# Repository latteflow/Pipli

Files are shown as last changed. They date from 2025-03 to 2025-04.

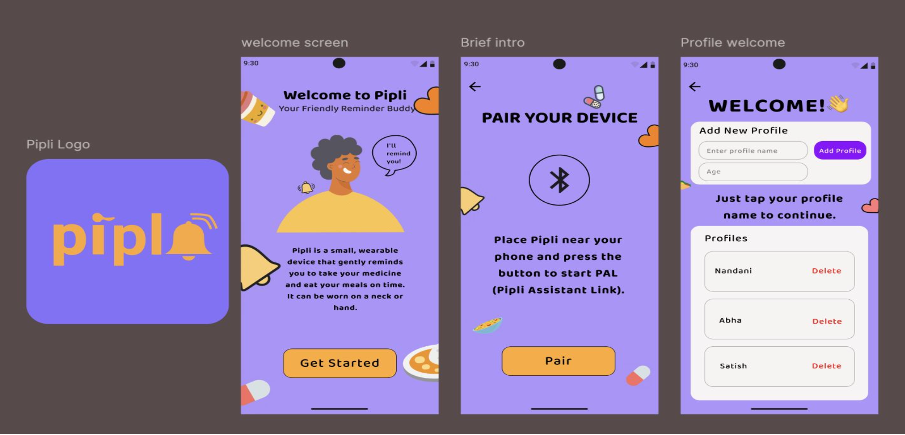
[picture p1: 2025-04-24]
App/Pipli/image.png

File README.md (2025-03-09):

# Pipli \- Medicine reminder device for elderly people.

A Device to help elderly people  
Github link: [https://github.com/latteflow/Pipli](https://github.com/latteflow/Pipli)  
Drawio file: 

Contributors: Nandani & Latteflow Team   
Started on: 21 January 2025

## Problem Statement 

Nowadays, most elderly people live alone at home. They often cannot leave because they are emotionally attached to their homes. However, living alone makes it difficult for them to take care of themselves. 

To solve this problem, we can create a low-cost device that provides timely reminders for meals and medication. This device can be worn on the wrist like a watch, making it easy to carry and use. It uses a low-cost microcontroller and a small ubiquitous replaceable battery. It can be easily connected to a smartphone via Bluetooth, where the reminders can be pre-programmed and saved in advance. The device will be easily accessible, ensuring elderly individuals receive important reminders without hassle.

The design and the code will be made open-source, such that everyone can access and easily replicate the design to help. 

We can create a device app called Pipli, which will feature a reminder system for important notifications. This app is designed to be highly convenient for elderly users, ensuring that they can easily set and receive reminders for various tasks and events. By focusing on a user-friendly interface with large buttons and clear instructions, Pipli will cater specifically to the needs of seniors, helping them manage their daily schedules effectively.

Approach 

![][image1]

This device will have a note chart for important items such as medication and food reminders. We can create a mockup of the app using Figma to ensure that everything is easy to understand. The app will include several features, such as buttons for help, sound notifications, feedback, and options for listening, downloading, or sharing information. This design will enhance user experience and make it more accessible for elderly users.

Do UX mockup of the app on the Figma 

1 Start writing a detailed approach 

- [ ] What is required   
- [ ] A smartphone with an application   
- [ ] Customizable options such as \- Repeat intervals, Advance alerts and Sound notifications.  
- [ ] A Pipli device to manage 

2 What functionality will the device have 

- [ ] Haptic feedback, ie, vibration   
- [ ] Sound   
- [ ] A button for Help  
- [ ] A button to listen   
- [ ] To create a new note  
- [ ] Delete Option  
- [ ] Share Option   
- [ ] Download Option

3 What components will it have 

- [ ] An MCU with WiFi/Bluetooth  
- [ ] Vibration motor   
- [ ] Sound   
- [ ] Button 

## 

## Electronics

Once each sensor and actuator has been tested and programmed individually, we have to design a PCB, which needs to be printed.   
Finally, we will solder every component and test it. When everything is working, then we will incorporate it into the mechanical housing 

KiCAD: [https://www.kicad.org/](https://www.kicad.org/)

![][image2]  
 Example PCB 

## Firmware

For programming and all: [https://platformio.org/](https://platformio.org/)

It has an extension for VS Code, please sign up and try to get it working

Website to simulate and run your program: [https://wokwi.com/esp32](https://wokwi.com/esp32)

## Mechanical Design 

Autodesk Fusion:   
[https://www.autodesk.com/in/products/fusion-360/overview](https://www.autodesk.com/in/products/fusion-360/overview)

Once the electronics are ready, we will start the mechanical design process. We will be utilizing the 3D printer for design iterations. 

Meanwhile, you should start designing the sketch, iterate, and think about user interactions and user experience. 

![][image3]

A Mockup of the Pipli device with Buttons

Fusion 360 Link for the design: 

[https://a360.co/4kiht4b](https://a360.co/4kiht4b)

## Application

Android / IOS   
[https://reactnative.dev/](https://reactnative.dev/)

We will have an app which will let the user connect and configure the reminders. It will be a primary way to connect to the device and save the program and reminders. Once the medicine course is over, it can be removed and a new medicine course can be saved for someone else. It will have the ability to connect to multiple devices.  

The app will be created in the React Native framework, such that both Android and IOS devices can work. 

UI / UX 

Figma:   
[https://www.figma.com/](https://www.figma.com/)

- [ ] PUT user interaction workflow here   

1. Press a button   
2. The device will wake up   
3. It will try to search for a new device   
4. If there is no device, then it will go into sleep mode   
5. Once the reminder comes close, it will wake up and try to play the sound/vibration sensor   
6. Once the user presses the button confirming they have taken medicine / do the work.   
7. Then it will go to sleep 

The user can ask for help by pressing the button   
If the device wakes and tries to connect with the smartphone, it will play the sound or send a notification that someone is in need of help.

## Components required 

ESP32

Tutorial: [https://randomnerdtutorials.com/projects-esp32/](https://randomnerdtutorials.com/projects-esp32/)

USB micro programmer / UBB C programmer 

LED 

Vibration motor: 

[https://robu.in/product/dc-vibration-motor-module/](https://robu.in/product/dc-vibration-motor-module/)

How to interface vibration motor with sensor: 

[https://thecustomizewindows.com/2021/08/esp32-and-coin-vibrator-motor/](https://thecustomizewindows.com/2021/08/esp32-and-coin-vibrator-motor/) 

Sound sensor: 

[https://www.elprocus.com/sound-sensor-working-and-its-applications/](https://www.elprocus.com/sound-sensor-working-and-its-applications/)

 Sound buzzers: 

[https://esp32io.com/tutorials/esp32-piezo-buzzer](https://esp32io.com/tutorials/esp32-piezo-buzzer)

[https://robu.in/product/5v-active-alarm-buzzer-module-arduino/](https://robu.in/product/5v-active-alarm-buzzer-module-arduino/)

Buttons or Tactile switch: 

[https://robu.in/product/6x6x5-tactile-push-button-switch/](https://robu.in/product/6x6x5-tactile-push-button-switch/)

Rechargeable battery: 

[https://robu.in/product/400mah-pcm-protected-micro-li-po-battery-2/](https://robu.in/product/400mah-pcm-protected-micro-li-po-battery-2/)

Lipo charger with USB C: 

[https://robu.in/product/lipo-charger-with-usc-c-type-jack/](https://robu.in/product/lipo-charger-with-usc-c-type-jack/)

[https://www.flyrobo.in/tp4056-1a-li-ion-lithium-battery-charging-module-with-current-protection-type-c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\&gQT=1](https://www.flyrobo.in/tp4056-1a-li-ion-lithium-battery-charging-module-with-current-protection-type-c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)

[https://robu.in/product/tp4056-1a-li-ion-lithium-battery-charging-module-with-current-protection-type-c/](https://robu.in/product/tp4056-1a-li-ion-lithium-battery-charging-module-with-current-protection-type-c/)

3d Printing service: [https://robu.in/product/3d-printing-service/](https://robu.in/product/3d-printing-service/)

2 List key steps

* Break down the journey into individual steps   
  Pipli Device \- Medicine Remainder  
- [ ] User interaction workflow  
1. Open the  phone go to the  bluetooth option and press the bluetooth  and open and see the Pipli device

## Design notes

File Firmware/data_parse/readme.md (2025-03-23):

Esp32: pinouts
http://randomnerdtutorials.com/esp32-pinout-reference-gpios/

Software dependencies: 
Make 
Platform IO 
Pio CLI 

## ESP32 
1. Make bluetooth work 
2. File sytem to Save JSON 
3. 

when pressing mechanical switches, it will debounce. The switch turn on and off multiple times before it settles.
This is due to the mechanical nature of the switch. To debounce, we can use a software solution.
The software solution is to wait for a certain amount of time before we consider the switch to be stable. This is called debouncing.

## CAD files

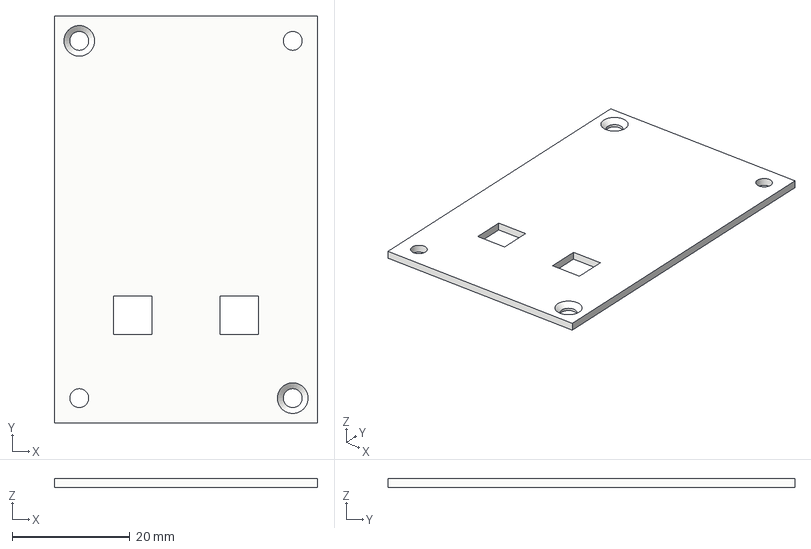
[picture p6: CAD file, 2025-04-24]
Mechanical/Pipli - TOP.step
44.6 x 69.0 x 1.50 mm

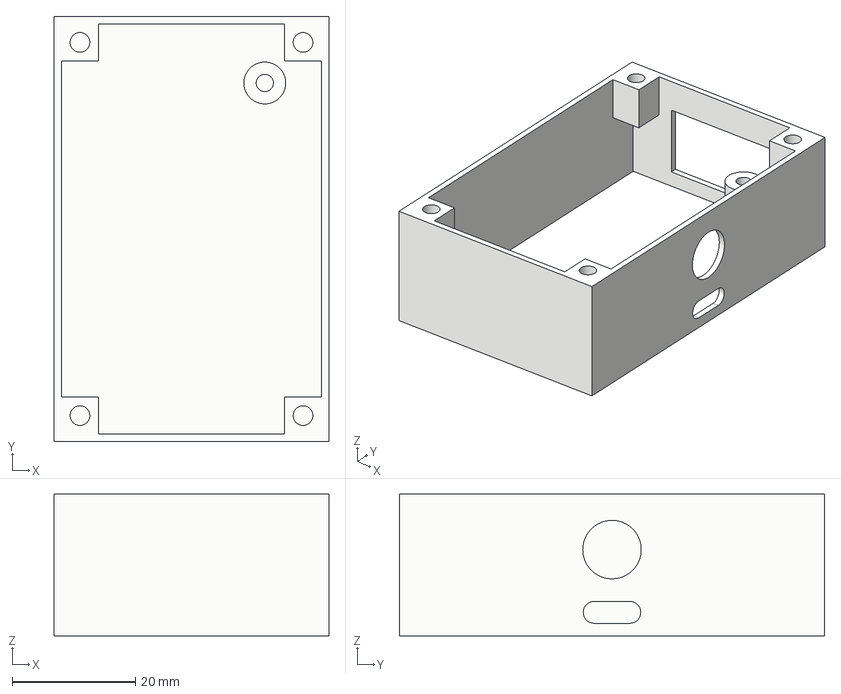
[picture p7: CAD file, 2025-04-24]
Mechanical/Pipli - BOTTOM.step
44.6 x 69.0 x 23.0 mm

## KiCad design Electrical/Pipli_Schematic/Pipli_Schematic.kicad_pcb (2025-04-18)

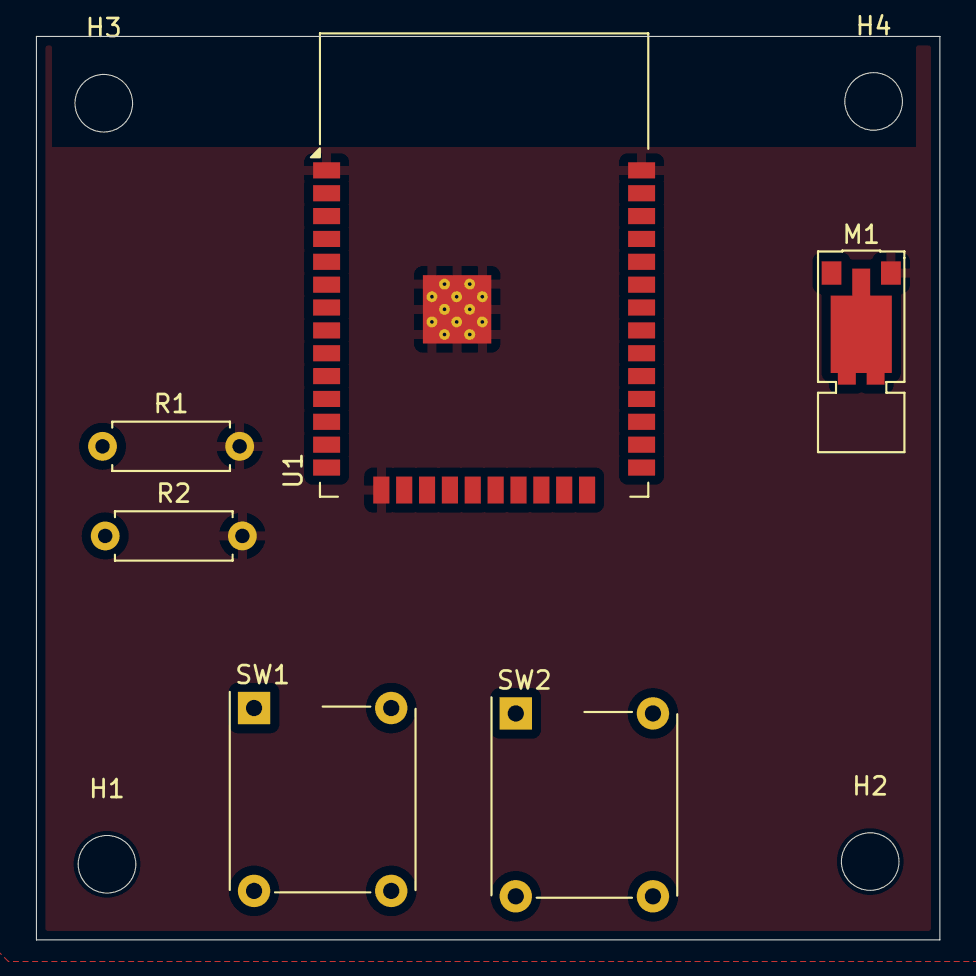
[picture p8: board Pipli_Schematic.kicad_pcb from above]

Board: 2 copper layers, 50.2 x 50.2 mm, 10 parts (0 on the bottom side), 4 nets, no tracks yet.

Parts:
H1, H2, H3, H4: M3; MountingHole_3.2mm_M3
M1: Motor_DC; Vybronics_VZ30C1T8219732L
R1, R2: 18k; R_Axial_DIN0207_L6.3mm_D2.5mm_P7.62mm_Horizontal
SW1, SW2: SW; SW_MEC_5GTH9
U1: ESP32-WROOM-32D

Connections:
/INPUT_SW_1: R1.1, SW1.1 (A), SW1.2 (A), U1.6 (IO34)
/INPUT_SW_2: R2.1, SW2.1 (A), SW2.2 (A), U1.37 (IO23)
/VIB_POS: M1.1 (+), U1.30 (IO18)
GND: M1.2 (-), R1.2, R2.2, U1.1 (GND), U1.15 (GND), U1.38 (GND), U1.39 (GND)

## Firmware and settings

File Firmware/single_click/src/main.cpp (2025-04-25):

#include <Arduino.h>

// bluetooth related
#include <BLEDevice.h>
#include <BLEServer.h>
#include <BLEUtils.h>
#include <BLE2902.h>

// srorage related (Optional but recommended for persistence)
#include "FS.h"
#include <LittleFS.h>

// JSON data library
#include <ArduinoJson.h>

#include <algorithm> // Needed for std::min

#define FORMAT_LITTLEFS_IF_FAILED true
#define SCHEDULE_FILENAME "/schedule.json"
#define MILLIS_COUNTER_FILENAME "/millis_counter.dat" // File to store last millis()

unsigned long lastMillisSaveTime = 0; // Timer for saving millis counter

BLEServer *pServer = NULL;
BLECharacteristic *pCharacteristic = NULL;
bool deviceConnected = false;
bool oldDeviceConnected = false;

// --- BLE Chunking Settings ---
const size_t BLE_CHUNK_SIZE = 20;
const int BLE_CHUNK_DELAY_MS = 30; // Delay between sending chunks (adjust as needed)

// See the following for generating UUIDs:
// https://www.uuidgenerator.net/

#define SERVICE_UUID "4fafc201-1fb5-459e-8fcc-c5c9c331914b"
#define CHARACTERISTIC_UUID "beb5483e-36e1-4688-b7f5-ea07361b26a8"

#define VIBRATION_PIN 19
#define PAIR_PIN 23 // Not used in reminder logic, but kept for consistency
#define USER_PIN 34 // Used for responding to reminders
#define LED 2

#define BLINK_DURATION_MS 50 // How long the LED stays on during a blink

// --- Reminder System Settings ---
#define VIBRATION_DURATION_MS 5000 // How long to vibrate for a reminder
#define RESPONSE_TIMEOUT_MS 15000  // How long to wait for user input after vibration

#define UPDATE_REQUEST_CMD "SEND_UPDATE"

// --- State Machine ---
enum State
{
    STATE_IDLE,                // Waiting for a schedule or connection
    STATE_PROCESSING_SCHEDULE, // Actively checking reminder times
    STATE_VIBRATING,           // Currently vibrating for a reminder
    STATE_WAITING_RESPONSE,    // Waiting for user button press after vibration
    STATE_SENDING_UPDATE       // Preparing/sending updated schedule
};
State currentState = STATE_IDLE;

// -- -Schedule Data-- -
// Use JsonDocument for flexibility. Adjust size as needed.
JsonDocument scheduleDoc; // Increased size for schedule + responses
bool scheduleLoaded = false;
unsigned long scheduleReceiveTime = 0; // millis() when schedule was received/loaded

// --- Reminder Tracking ---
int currentMedIndex = -1;
int currentTimeIndex = -1;
unsigned long stateTimer = 0;                // Used for vibration duration and response timeout
unsigned long nextReminderDueTimeMillis = 0; // Stores the absolute time of the next reminder
unsigned long lastCountdownPrintMillis = 0;  // Timer for printing countdown

// -- -Function Prototypes-- -
void blinkLed();
void startVibration();
void stopVibration();
bool loadSchedule();
bool saveSchedule();
void processSchedule();
void sendUpdate(bool changeStateToIdleOnSuccess = true);
// void moveToNextReminder(); // No longer needed
void handleReceivedData(const std::string &data);

bool saveMillisCounter();
unsigned long loadMillisCounter();

// Stream opearator (kept from original)
template <class T>
inline Print &operator<<(Print &obj, T arg)
{
    obj.print(arg);
    return obj;
}
template <>
inline Print &operator<<(Print &obj, float arg)
{
    obj.print(arg, 4);
    return obj;
}
// It preserves the original LED state if it was meant to be ON (connected)
void blinkLed()
{
    bool originalState = digitalRead(LED);
    digitalWrite(LED, !originalState);
    delay(BLINK_DURATION_MS);
    digitalWrite(LED, originalState);
}

void startVibration()
{
    Serial.println("Starting Vibration");
    digitalWrite(VIBRATION_PIN, HIGH);
}

void stopVibration()
{
    Serial.println("Stopping Vibration");
    digitalWrite(VIBRATION_PIN, LOW);
}

class MyServerCallbacks : public BLEServerCallbacks
{
    void onConnect(BLEServer *pServer)
    {
        deviceConnected = true;
        digitalWrite(LED, HIGH); // LED ON when connected
        Serial.println("Device Connected");
        // Optional: Maybe request schedule update on connect?
        // pCharacteristic->setValue("REQUEST_SCHEDULE");
        // pCharacteristic->notify();
    };

    void onDisconnect(BLEServer *pServer)
    {
        deviceConnected = false;
        digitalWrite(LED, LOW); // LED OFF when disconnected
        Serial.println("Device Disconnected - Restarting Advertising");
        // Reset state if needed when disconnected? Maybe not, allow processing offline.
        // currentState = STATE_IDLE;
        // scheduleLoaded = false;
        delay(500);                  // Give stack time
        pServer->startAdvertising(); // Restart advertising
    }
};

class MyCharacteristicCallbacks : public BLECharacteristicCallbacks
{
    void onWrite(BLECharacteristic *pCharacteristic)
    {
        std::string rxValue = pCharacteristic->getValue();
        if (rxValue.length() > 0)
        {
            Serial.println(" ");
            Serial.print("Received data: ");
            Serial.println(rxValue.c_str());
            blinkLed(); // Blink on any receive

            // --- Modification: Check for command first ---
            if (rxValue == UPDATE_REQUEST_CMD)
            {
                Serial.println("Received update request command.");
                // Attempt to send the update immediately if connected
                // sendUpdate() already checks for connection and loaded data
                sendUpdate(false);
            }
            else
            {
                // If it's not the command, assume it's a new schedule
                Serial.println("Data is not an update command, treating as new schedule.");
                handleReceivedData(rxValue);
            }
            // --- End Modification ---
        }
    }
};

// --- Function to save the current millis() counter ---
bool saveMillisCounter()
{
    unsigned long currentMillis = millis();
    File file = LittleFS.open(MILLIS_COUNTER_FILENAME, FILE_WRITE); // Open for writing (overwrite)
    if (!file)
    {
        Serial.println("Failed to open millis counter file for writing");
        return false;
    }

    // Write the current millis() value as binary data
    size_t bytesWritten = file.write((uint8_t *)&currentMillis, sizeof(currentMillis));
    file.close();

    if (bytesWritten == sizeof(currentMillis))
    {
        // Serial.printf("Millis counter saved: %lu\n", currentMillis); // Optional: Verbose logging
        return true;
    }
    else
    {
        Serial.println("Failed to write millis counter to file.");
        LittleFS.remove(MILLIS_COUNTER_FILENAME); // Attempt to remove potentially corrupted file
        return false;
    }
}

// --- Function to load the last saved millis() counter ---
unsigned long loadMillisCounter()
{
    if (!LittleFS.exists(MILLIS_COUNTER_FILENAME))
    {
        Serial.println("Millis counter file not found.");
        return 0; // Return 0 if no previous value exists
    }

    File file = LittleFS.open(MILLIS_COUNTER_FILENAME, FILE_READ);
    if (!file)
    {
        Serial.println("Failed to open millis counter file for reading");
        return 0;
    }

    unsigned long loadedMillis = 0;
    if (file.size() == sizeof(loadedMillis))
    {
        size_t bytesRead = file.read((uint8_t *)&loadedMillis, sizeof(loadedMillis));
        if (bytesRead != sizeof(loadedMillis))
        {
            Serial.println("Error reading millis counter file.");
            loadedMillis = 0; // Treat read error as if file didn't exist
        }
    }
    else
    {
        Serial.println("Millis counter file has incorrect size.");
        loadedMillis = 0; // Treat size error as if file didn't exist
    }

    file.close();

    if (loadedMillis > 0)
    {
        Serial.printf("Loaded last known millis: %lu\n", loadedMillis);
    }
    return loadedMillis;
}

// --- Schedule Handling Logic ---

void handleReceivedData(const std::string &data)
{
    Serial.println("Attempting to parse NEW schedule data string...");

    // --- Parse the incoming data string as a temporary array ---
    JsonDocument tempDoc; // Use a temporary document for the incoming array
    DeserializationError tempError = deserializeJson(tempDoc, data);
    if (tempError)
    {
        Serial.print(F("Initial parsing of received string failed: "));
        Serial.println(tempError.f_str());
        // Don't change state or clear existing valid schedule if parsing fails
        return;
    }
    if (!tempDoc.is<JsonArray>())
    {
        Serial.println("Error: Received data string is not a JSON array.");
        return;
    }
    JsonArray receivedArray = tempDoc.as<JsonArray>();
    // --- End temporary parsing ---

    // --- Prepare the main scheduleDoc with the new structure ---
    scheduleDoc.clear();                            // Clear previous data
    JsonObject root = scheduleDoc.to<JsonObject>(); // Make the root an object
    JsonArray scheduleArray = root.createNestedArray("schedule");
    if (scheduleArray.isNull())
    {
        Serial.println("Error: Failed to create nested schedule array. Memory full?");
        scheduleLoaded = false; // Mark as not loaded
        currentState = STATE_IDLE;
        return;
    }
    // --- End structure preparation ---

    // --- Populate the new schedule array with structured time objects ---
    bool structureUpdateSuccess = true;
    for (JsonObject med_in : receivedArray)
    { // Iterate the temporary parsed array
        // Create a corresponding object in the main scheduleDoc's array
        JsonObject med_out = scheduleArray.createNestedObject();
        if (med_out.isNull())
        {
            Serial.println("Error: Failed to create medication object. Memory full?");
            structureUpdateSuccess = false;
            break;
        }
        // Copy necessary fields (adjust if you have more fields)
        med_out["med_id"] = med_in["med_id"]; // Assuming med_id exists

        if (med_in.containsKey("times") && med_in["times"].is<JsonArray>())
        {
            JsonArray times_in = med_in["times"].as<JsonArray>();
            JsonArray times_out = med_out.createNestedArray("times");
            if (times_out.isNull())
            {
                Serial.println("Error: Failed to create nested times array. Memory full?");
                structureUpdateSuccess = false;
                break;
            }

            for (JsonVariant t_in : times_in)
            {
                JsonObject timeObj_out = times_out.createNestedObject();
                if (timeObj_out.isNull())
                {
                    Serial.println("Error: Failed to create nested time object. Memory full?");
                    structureUpdateSuccess = false;
                    break;
                }
                timeObj_out["time"] = t_in.as<String>(); // Copy time offset
                timeObj_out["responded"] = nullptr;      // Initialize responded state
            }
            if (!structureUpdateSuccess)
                break;
        }
        else
        {
            Serial.println("Warning: Medication entry missing 'times' array or invalid format.");
            // Handle as needed, maybe skip this medication entry
        }
    } // --- End populating ---

    if (!structureUpdateSuccess)
    {
        Serial.println("Failed to build new schedule structure. Aborting.");
        scheduleLoaded = false;
        currentState = STATE_IDLE;
        scheduleDoc.clear(); // Clear potentially corrupted document
        return;
    }

    // --- Store the original receive time ---
    scheduleReceiveTime = millis();                    // Get the current time
    root["originalReceiveTime"] = scheduleReceiveTime; // Store it in the JSON object
    // --- End storing time ---

    Serial.println("New schedule processed and structured successfully.");
    Serial.printf("Original Receive Time recorded: %lu\n", scheduleReceiveTime);

    // --- Debug: Print the modified structure ---
    Serial.println("--- New Schedule Structure ---");
    serializeJsonPretty(scheduleDoc, Serial);
    Serial.println("\n----------------------------");

    scheduleLoaded = true;
    // Reset indices - processSchedule will find the first one
    currentMedIndex = -1;
    currentTimeIndex = -1;
    currentState = STATE_PROCESSING_SCHEDULE;
    Serial.println("State changed to STATE_PROCESSING_SCHEDULE");

    // Save the new schedule (with timestamp)
    if (!saveSchedule())
    {
        Serial.println("Error saving new schedule!");
        // Handle error? Maybe revert state?
    }
}

// --- MODIFIED processSchedule ---
// Scans the entire schedule to find the earliest *absolute* time for the next reminder
void processSchedule()
{
    if (!scheduleLoaded || !scheduleDoc.is<JsonObject>() || !scheduleDoc.containsKey("schedule"))
    {
        currentState = STATE_IDLE;
        return;
    }

    JsonArray scheduleArray = scheduleDoc["schedule"].as<JsonArray>();
    unsigned long currentTimeMillis = millis();

    // Variables to track the earliest due reminder found in this scan
    unsigned long earliestDueTimeFound = 0; // Use 0 as initial, check if set later
    int earliestMedIndexFound = -1;
    int earliestTimeIndexFound = -1;
    bool reminderFound = false; // Flag if we found *any* unprocessed reminder

    // Scan ALL medications and ALL times
    for (int medIdx = 0; medIdx < scheduleArray.size(); ++medIdx)
    {
        JsonObject currentMed = scheduleArray[medIdx];
        // Basic validation for the medication entry
        if (!currentMed || !currentMed.containsKey("times") || !currentMed["times"].is<JsonArray>())
        {
            // Serial.printf("Skipping invalid med entry at index %d\n", medIdx); // Optional debug
            continue; // Skip to next medication
        }

        JsonArray timesArray = currentMed["times"].as<JsonArray>();
        for (int timeIdx = 0; timeIdx < timesArray.size(); ++timeIdx)
        {
            JsonObject timeObj = timesArray[timeIdx];
            // Basic validation for the time entry
            if (!timeObj || !timeObj.containsKey("time") || !timeObj.containsKey("responded"))
            {
                // Serial.printf("Skipping invalid time entry at med %d, time %d\n", medIdx, timeIdx); // Optional debug
                continue; // Skip to next time
            }

            // Check if this reminder needs processing (responded is null)
            if (timeObj["responded"].isNull())
            {
                // Calculate its absolute due time
                long reminderOffsetSeconds = timeObj["time"].as<String>().toInt();
                unsigned long reminderDueTimeMillis = scheduleReceiveTime + (reminderOffsetSeconds * 1000UL);

                // Compare with the earliest found so far
                if (!reminderFound || reminderDueTimeMillis < earliestDueTimeFound)
                {
                    earliestDueTimeFound = reminderDueTimeMillis;
                    earliestMedIndexFound = medIdx;
                    earliestTimeIndexFound = timeIdx;
                    reminderFound = true; // Mark that we found at least one
                }
            }
        } // End loop times
    } // End loop medications

    // --- After scanning everything ---

    if (reminderFound)
    {
        // We found at least one unprocessed reminder. Check if the earliest one is due.
        // Serial.printf("Earliest reminder found: Med %d, Time %d, Due: %lu, Now: %lu\n", // Debug
        //               earliestMedIndexFound, earliestTimeIndexFound, earliestDueTimeFound, currentTimeMillis);

        if (currentTimeMillis >= earliestDueTimeFound)
        {
            // It's time! Set the global indices for the active reminder
            currentMedIndex = earliestMedIndexFound;
            currentTimeIndex = earliestTimeIndexFound;

            // Get details for logging
            JsonObject med = scheduleArray[currentMedIndex];
            JsonObject time = med["times"].as<JsonArray>()[currentTimeIndex];

            Serial.printf("Reminder Due! Med ID: %s, Time Offset: %s (Indices: M%d, T%d)\n",
                          med["med_id"].as<const char *>(),
                          time["time"].as<const char *>(),
                          currentMedIndex, currentTimeIndex);

            startVibration();
            stateTimer = millis(); // Start timer for vibration duration
            currentState = STATE_VIBRATING;
            Serial.println("State changed to STATE_VIBRATING");
        }
        // Else: An unprocessed reminder exists, but it's not time yet. Stay in PROCESSING state.
        nextReminderDueTimeMillis = earliestDueTimeFound; // Store the time for the countdown
    }
    else
    {
        nextReminderDueTimeMillis = 0; // Reset when no reminders are pending

        // No unprocessed reminders were found in the entire schedule.
        Serial.println("All medications processed.");
        if (deviceConnected)
        {
            currentState = STATE_SENDING_UPDATE;
            Serial.println("Processing complete. State changed to STATE_SENDING_UPDATE.");
        }
        else
        {
            currentState = STATE_IDLE;
            Serial.println("Processing complete while disconnected. Update pending. State changed to STATE_IDLE.");
        }
    }
}
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
void loop()
{

    // --- Periodically save millis counter ---
    // Only save if a schedule is loaded, otherwise, the counter isn't very useful
    if (scheduleLoaded && (millis() - lastMillisSaveTime >= 5000))
    {
        lastMillisSaveTime = millis();
        saveMillisCounter(); // Attempt to save the current millis() value
    }
    // --- End periodic save ---

    // --- Handle Connection State Changes (Advertising) ---
    // This logic is mostly handled by callbacks now, but keep advertising restart logic
    if (!deviceConnected && oldDeviceConnected)
    {
        // onDisconnect callback handles LED and prints message
        // It also restarts advertising
        oldDeviceConnected = deviceConnected;
    }
    if (deviceConnected && !oldDeviceConnected)
    {
        // onConnect callback handles LED and prints message
        oldDeviceConnected = deviceConnected;
    }

    // --- Main State Machine ---
    switch (currentState)
    {
    case STATE_IDLE:
        // Waiting for connection or schedule via BLE write
        // Or waiting for a command like "SEND_UPDATE" if implemented
        // Low power mode could potentially be entered here if idle for long
        break;

    case STATE_PROCESSING_SCHEDULE:
        // Check the schedule for due reminders
        processSchedule();

        // --- Add Countdown Logic ---
        if (millis() - lastCountdownPrintMillis >= 1000)
        {
            lastCountdownPrintMillis = millis();
            if (nextReminderDueTimeMillis > 0)
            {
                unsigned long now = millis();
                // nextReminderDueTimeMillis is calculated based on the adjusted scheduleReceiveTime
                if (nextReminderDueTimeMillis > now)
                {
                    unsigned long remainingMillis = nextReminderDueTimeMillis - now;
                    unsigned long remainingSeconds = remainingMillis / 1000;
                    Serial.printf("Next reminder in: %lu seconds\n", remainingSeconds);
                }
                else
                {
                    // Serial.println("Next reminder is due now or very soon.");
                }
            }
            else
            {
                if (scheduleLoaded)
                {
                    Serial.println("No pending reminders.");
                }
            }
        }
        // --- End Countdown Logic ---
        break;

    case STATE_VIBRATING:
        // Check if vibration duration has passed
        if (millis() - stateTimer >= VIBRATION_DURATION_MS)
        {
            stopVibration();
            stateTimer = millis(); // Start timer for response timeout
            currentState = STATE_WAITING_RESPONSE;
            Serial.println("State changed to STATE_WAITING_RESPONSE");
        }
        break;

    case STATE_WAITING_RESPONSE:
        // Check for user button press
        if (digitalRead(USER_PIN) == HIGH)
        {
            Serial.println("User button pressed - Responded YES");
            recordResponse(true); // Records response, saves, moves to next, sets state back
            // Debounce delay might be needed if button is bouncy
            delay(200);
        }
        // Check for response timeout
        else if (millis() - stateTimer >= RESPONSE_TIMEOUT_MS)
        {
            Serial.println("Response timeout - Responded NO");
            recordResponse(false); // Records response, saves, moves to next, sets state back
        }
        break;

    case STATE_SENDING_UPDATE:
        // Attempt to send the update
        sendUpdate();
        // If sendUpdate was called but couldn't send (because device was disconnected),
        // it would have returned without changing the state. We should transition
        // back to IDLE here, as the "sending attempt" is done for this cycle.
        // The data remains loaded for a future request.
        // If sendUpdate *did* send successfully, it already set the state to IDLE.
        if (currentState == STATE_SENDING_UPDATE)
        { // Check if sendUpdate didn't already change state
            Serial.println("Send attempt finished (or skipped if disconnected). Returning to IDLE.");
            currentState = STATE_IDLE;
        }
        break;
    }

    // Small delay to prevent watchdog issues if loop is very fast
    delay(10);
} // End loop

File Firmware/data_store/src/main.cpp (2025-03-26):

#include <Arduino.h>
#include "FS.h"
#include <LittleFS.h>

// JSON data library
#include <ArduinoJson.h>

#define FORMAT_LITTLEFS_IF_FAILED true

void listDir(fs::FS &fs, const char *dirname, uint8_t levels)
{
  Serial.printf("Listing directory: %s\r\n", dirname);

  File root = fs.open(dirname);
  if (!root)
  {
    Serial.println("- failed to open directory");
    return;
  }
  if (!root.isDirectory())
  {
    Serial.println(" - not a directory");
    return;
  }

  File file = root.openNextFile();
  while (file)
  {
    if (file.isDirectory())
    {
      Serial.print("  DIR : ");
      Serial.println(file.name());
      if (levels)
      {
        listDir(fs, file.path(), levels - 1);
      }
    }
    else
    {
      Serial.print("  FILE: ");
      Serial.print(file.name());
      Serial.print("\tSIZE: ");
      Serial.println(file.size());
    }
    file = root.openNextFile();
  }
}

void createDir(fs::FS &fs, const char *path)
{
  Serial.printf("Creating Dir: %s\n", path);
  if (fs.mkdir(path))
  {
    Serial.println("Dir created");
  }
  else
  {
    Serial.println("mkdir failed");
  }
}

void removeDir(fs::FS &fs, const char *path)
{
  Serial.printf("Removing Dir: %s\n", path);
  if (fs.rmdir(path))
  {
    Serial.println("Dir removed");
  }
  else
  {
    Serial.println("rmdir failed");
  }
}

void readFile(fs::FS &fs, const char *path)
{
  Serial.printf("Reading file: %s\r\n", path);

  File file = fs.open(path);
  if (!file || file.isDirectory())
  {
    Serial.println("- failed to open file for reading");
    return;
  }

  JsonDocument doc;
  deserializeJson(doc, file);
  const char *sensor = doc["sensor"];
  long time = doc["time"];
  double latitude = doc["data"][0];
  double longitude = doc["data"][1];

  Serial.println(sensor);
  Serial.println(time);
  Serial.println(latitude, 6);
  Serial.println(longitude, 6);
  Serial.println("Json parse working");

  Serial.println("- read from file:");
  while (file.available())
  {
    Serial.write(file.read());
  }
  file.close();
}

void writeFile(fs::FS &fs, const char *path, const char *message)
{
  Serial.printf("Writing file: %s\r\n", path);

  File file = fs.open(path, FILE_WRITE);
  if (!file)
  {
    Serial.println("- failed to open file for writing");
    return;
  }
  if (file.print(message))
  {
    Serial.println("- file written");
  }
  else
  {
    Serial.println("- write failed");
  }
  file.close();
}

void appendFile(fs::FS &fs, const char *path, const char *message)
{
  Serial.printf("Appending to file: %s\r\n", path);

  File file = fs.open(path, FILE_APPEND);
  if (!file)
  {
    Serial.println("- failed to open file for appending");
    return;
  }
  if (file.print(message))
  {
    Serial.println("- message appended");
  }
  else
  {
    Serial.println("- append failed");
  }
  file.close();
}

void renameFile(fs::FS &fs, const char *path1, const char *path2)
{
  Serial.printf("Renaming file %s to %s\r\n", path1, path2);
  if (fs.rename(path1, path2))
  {
    Serial.println("- file renamed");
  }
  else
  {
    Serial.println("- rename failed");
  }
}

void deleteFile(fs::FS &fs, const char *path)
{
  Serial.printf("Deleting file: %s\r\n", path);
  if (fs.remove(path))
  {
    Serial.println("- file deleted");
  }
  else
  {
    Serial.println("- delete failed");
  }
}

void testFileIO(fs::FS &fs, const char *path)
{
  Serial.printf("Testing file I/O with %s\r\n", path);

  static uint8_t buf[512];
  size_t len = 0;
  File file = fs.open(path, FILE_WRITE);
  if (!file)
  {
    Serial.println("- failed to open file for writing");
    return;
  }

  size_t i;
  Serial.print("- writing");
  uint32_t start = millis();
  for (i = 0; i < 2048; i++)
  {
    if ((i & 0x001F) == 0x001F)
    {
      Serial.print(".");
    }
    file.write(buf, 512);
  }
  Serial.println("");
  uint32_t end = millis() - start;
  Serial.printf(" - %u bytes written in %lu ms\r\n", 2048 * 512, end);
  file.close();

  file = fs.open(path);
  start = millis();
  end = start;
  i = 0;
  if (file && !file.isDirectory())
  {
    len = file.size();
    size_t flen = len;
    start = millis();
    Serial.print("- reading");
    while (len)
    {
      size_t toRead = len;
      if (toRead > 512)
      {
        toRead = 512;
      }
      file.read(buf, toRead);
      if ((i++ & 0x001F) == 0x001F)
      {
        Serial.print(".");
      }
      len -= toRead;
    }
    Serial.println("");
    end = millis() - start;
    Serial.printf("- %u bytes read in %lu ms\r\n", flen, end);
    file.close();
  }
  else
  {
    Serial.println("- failed to open file for reading");
  }
}

void setup()
{
  Serial.begin(115200);

  if (!LittleFS.begin(FORMAT_LITTLEFS_IF_FAILED))
  {
    Serial.println("LittleFS Mount Failed");
    return;
  }

  // JSON input string.
  const char *json = "{\"sensor\":\"gps\",\"time\":1351824120,\"data\":[48.756080,2.302038]}";
  delay(3000);
  listDir(LittleFS, "/", 3);
  createDir(LittleFS, "/mydir");
  writeFile(LittleFS, "/mydir/hello.txt", json);
  listDir(LittleFS, "/", 1);
  readFile(LittleFS, "/mydir/hello.txt");
}

void loop() {}

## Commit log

2025-03-09 write button press code
2025-03-23 add esp32 client
2025-03-25 data parse and data save working
    [partitions.csv]
2025-03-25 data parsing working inside readme file
    [partitions.csv]
2025-03-26 compile for other board as well
2025-04-24 add step file
    [Pipli - BOTTOM.step, Pipli - TOP.step]
